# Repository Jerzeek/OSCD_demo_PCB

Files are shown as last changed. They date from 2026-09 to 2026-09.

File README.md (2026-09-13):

# OSCD Demo PCB

A demonstration / teaching PCB built by the [Open Science Community Delft](https://www.tudelft.nl/en/library/open-science-community-delft) to show what an open hardware project looks like in practice: full sources, an open licence, and everything needed to have the board made and reprogrammed by anyone.

It is a round, ~93 mm ESP32-C3 board shaped like the OSCD logo, with a ring of 12 addressable RGB LEDs, three sensors on a shared I²C bus, capacitive touch pads, and three push buttons. Plug it into USB-C, and the demo firmware lights the ring in response to tilt, touch, ambient light, and button presses.

| | |
|---|---|
| **Revision** | 1.0 |
| **Designer** | Dr. ir. Tim M. J. Nijssen, Open Science Community Delft |
| **Licence** | [CERN-OHL-P v2](LICENSE) (permissive) |
| **EDA tool** | KiCad (2026-era release — see [Opening the design](#opening-the-design)) |

---

## Features

| Block | Part | Interface |
|---|---|---|
| Microcontroller | ESP32-C3-MINI-1 (RISC-V, Wi-Fi + BLE, native USB) | — |
| RGB LEDs | 12 × WS2812B-2020, in a 63 mm ring | 1-wire, `GPIO8` |
| IMU | LSM6DS3 — 3-axis accelerometer + gyroscope | I²C `0x6A` |
| Ambient light | APDS-9306-065 | I²C `0x52` |
| Capacitive touch | MPR121 — 12 electrodes (6 buttons + 6-pad slider) | I²C `0x5A`, IRQ on `GPIO10` |
| Buttons | 3 × user push button, plus RESET and BOOT | `GPIO0/1/2` |
| Power | USB-C 5 V → HT7533-1 LDO → 3.3 V | — |
| Breakout | 2 × 2×5 pin header (5 V, 3.3 V, GND, 9 GPIO) | 2.54 mm |
| Test points | 5 V, 3.3 V, SDA, SCL (each via 100 Ω) | — |

There is no USB-UART bridge — the ESP32-C3's native USB peripheral is wired straight to the USB-C connector, protected by a USBLC6-2SC6 ESD array.

## Quick start

1. **Power it.** Connect a USB-C cable to `J1`. The board is bus-powered; no battery or jumper setting is needed.
2. **Install the toolchain.** Arduino IDE with the *esp32* board package by Espressif, board **ESP32C3 Dev Module**, and **Tools → USB CDC On Boot: Enabled**.
3. **Flash the demo.** Open [`firmware_examples/test_sensors/test_sensors.ino`](firmware_examples/test_sensors/test_sensors.ino) and upload it. Because there is no auto-reset circuit you must enter the bootloader by hand: **hold BOOT (SW2), tap RESET (SW1), release BOOT**, then click Upload. Tap RESET again when the upload finishes.
4. **Watch it.** The ring plays a rainbow sweep at boot, then reacts to tilt, touch, and the three buttons. Open the Serial Monitor at 115200 baud for sensor readings.

Full setup notes, required libraries, and troubleshooting are in [`firmware_examples/README.md`](firmware_examples/README.md).

## Pinout

| ESP32-C3 pin | Function on this board | Also on |
|---|---|---|
| `GPIO0` | Button **SW4** (active low, RC-debounced) | `J2.6` |
| `GPIO1` | Button **SW3** (active low, RC-debounced) | `J2.7` |
| `GPIO2` | Button **SW5** (active low, RC-debounced) | `J2.3` |
| `GPIO3` | APDS-9306 interrupt | `J2.4` |
| `GPIO4` | LSM6DS3 `INT1` | `J2.9` |
| `GPIO5` | LSM6DS3 `INT2` | `J3.3` |
| `GPIO6` | **I²C SCL** (4.7 kΩ pull-up) | `J3.4`, `TP5` |
| `GPIO7` | **I²C SDA** (4.7 kΩ pull-up) | `J3.5`, `TP6` |
| `GPIO8` | WS2812B data out → `D1` | `J3.6` |
| `GPIO9` | BOOT button **SW2** (strapping pin) | `J3.7` |
| `GPIO10` | MPR121 `IRQ` | `J2.8` |
| `GPIO18/19` | USB D− / D+ | — |
| `GPIO20/21` | UART0 RX / TX | `J3.8`, `J3.9` |
| `EN` | RESET button **SW1** | `J2.5` |

**Header pinouts** (2×5, 2.54 mm, odd/even numbering):

```
J2:  1 +5V    2 +3V3    3 GPIO2   4 GPIO3   5 EN
     6 GPIO0  7 GPIO1   8 GPIO10  9 GPIO4  10 GND

J3:  1 +5V    2 +3V3    3 GPIO5   4 GPIO6   5 GPIO7
     6 GPIO8  7 GPIO9   8 GPIO20  9 GPIO21 10 GND
```

**LED ring order:** `D1` sits at the 9 o'clock position and the chain `D1 → D2 → … → D12` runs clockwise, 30° apart.

**Touch electrodes:** `TP2` is the inner 6-pad slider on `ELE0…ELE5`; `TP1` is the outer ring of 6 buttons on `ELE6…ELE11`.

## Repository layout

```
OSCD_demo_PCB.kicad_pro     KiCad project
OSCD_demo_PCB.kicad_sch     Schematic (single sheet)
OSCD_demo_PCB.kicad_pcb     Board layout (4 layers)
schematic.pdf               Rendered schematic, for reading without KiCad
assets/
  OSCD_demo_PCB_symbols.kicad_sym    Project-local symbols
  OSCD_demo_PCB_footprints.pretty/   Project-local footprints (ESP32 module,
                                     touch pads, WS2812B-2020, logo, switches)
  graphics/                          OSCD logo artwork (DXF)
bom/ibom.html               Interactive HTML BOM for hand assembly
production/                 Fabrication outputs (gerbers, drill, BOM, CPL)
firmware_examples/          Arduino sketches
docs/                       Hardware and manufacturing documentation
```

## Opening the design

The sources were saved by a 2026-era KiCad release (schematic file format `20260306`, board format `20260206`). Open them with that release or newer; older KiCad versions will refuse the files.

Symbol and footprint libraries are project-local and resolved through `${KIPRJMOD}` in `sym-lib-table` / `fp-lib-table`, so cloning the repository and opening `OSCD_demo_PCB.kicad_pro` is enough — nothing has to be installed into your global libraries.

## Documentation

- **[docs/hardware.md](docs/hardware.md)** — how each subsystem works, jumper/configuration options, and design notes.
- **[docs/manufacturing.md](docs/manufacturing.md)** — board specification, ordering, and how to regenerate the fabrication files.
- **[firmware_examples/README.md](firmware_examples/README.md)** — toolchain setup, upload procedure, and what the demo does.

## Licence

Hardware and firmware are released under the **CERN Open Hardware Licence Version 2 – Permissive** ([`LICENSE`](LICENSE)). You may use, study, modify, manufacture and sell boards based on this design, including in closed-source products, provided you keep the copyright and licence notices and do not imply endorsement.

The OSCD logo and name are project branding; please replace them with your own if you distribute modified boards.

## Credits

Designed by Dr. ir. Tim M. J. Nijssen for the Open Science Community Delft.

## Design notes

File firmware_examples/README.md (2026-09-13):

# Firmware examples

Arduino sketches for the OSCD Demo PCB rev 1.0.

| Sketch | What it does |
|---|---|
| [`test_sensors/`](test_sensors) | Exercises every subsystem on the board — LEDs, IMU, light sensor, touch pads and buttons. Use it as a bring-up test and as a starting point for your own code. |

## Toolchain setup

1. Install the **Arduino IDE**.
2. **Boards Manager** → install **esp32** by Espressif Systems.
3. **Tools → Board** → *ESP32C3 Dev Module*.
4. **Tools → USB CDC On Boot** → **Enabled**. This is required. The board has no USB-UART bridge, so `Serial` runs over the ESP32-C3's native USB peripheral and will not appear at all if CDC is left disabled.
5. **Library Manager** → install:
   - `Adafruit NeoPixel`
   - `Adafruit LSM6DS` (pulls in `Adafruit_LSM6DS3TRC`)
   - `Adafruit Unified Sensor`
   - `Adafruit MPR121`

The APDS-9306-065 light sensor has no widely available Arduino library, so `test_sensors` talks to it directly over `Wire`. Those helpers live in [`test_sensors/APDS9306.h`](test_sensors/APDS9306.h) and double as a compact example of raw I²C register access.

## Uploading

There is no auto-reset circuit on this board, so the bootloader is entered by hand:

1. Close every open Serial Monitor — an open port blocks the upload.
2. **Hold BOOT (`SW2`).**
3. **Tap RESET (`SW1`).**
4. **Release BOOT.**
5. Click **Upload** in the IDE.
6. When the upload finishes, **tap RESET** to start the new firmware.

If the port does not appear, repeat steps 2–4; in bootloader mode the board enumerates under a different name than when running your sketch.

## What `test_sensors` does

On boot the ring plays a two-turn rainbow sweep, then the sketch runs continuously:

| Input | Effect |
|---|---|
| Buttons `SW3`/`SW4`/`SW5` | Each lights one third of the ring (4 LEDs) in its own hue while held |
| Tilt (LSM6DS3) | A red dot tracks the direction of gravity around the ring; brightness follows tilt magnitude |
| Ambient light (APDS-9306) | Scales overall ring brightness, so the board dims in a dark room |
| Touch pads (MPR121) | Each of the 12 electrodes lights its matching LED, brightness following touch strength |

Every 500 ms the sketch prints IMU, light and touch readings to **Serial at 115200 baud**. Each subsystem is probed at startup and reported as `[OK]` or `[FAIL]`, and the main loop skips whatever did not answer — so a single unpopulated or badly soldered sensor will not stop the rest of the board from working. That makes the sketch a useful first test on a freshly assembled board.

## Pin reference

```
I2C SDA        GPIO7    LSM6DS3 @0x6A, APDS-9306-065 @0x52, MPR121 @0x5A
I2C SCL        GPIO6
WS2812 data    GPIO8    12 LEDs, D1 at 9 o'clock, chain runs clockwise
Button SW3     GPIO1    active low
Button SW4     GPIO0    active low
Button SW5     GPIO2    active low
MPR121 IRQ     GPIO10   unused by this sketch
LSM6DS3 INT1   GPIO4    unused by this sketch
LSM6DS3 INT2   GPIO5    unused by this sketch
```

Buttons have external pull-ups and RC debouncing on the board, so `pinMode(pin, INPUT)` is correct — do not enable `INPUT_PULLUP`.

## Troubleshooting

| Symptom | Likely cause |
|---|---|
| No serial port at all | *USB CDC On Boot* is disabled, or a data-less charge-only USB-C cable |
| Upload fails / port vanishes | Serial Monitor still open, or the BOOT/RESET sequence was not held long enough |
| `[FAIL]` on one sensor | Solder bridge or open joint on that IC — check continuity on SDA/SCL at `TP6`/`TP5` |
| All I²C devices fail | `R15`/`R16` pull-ups missing, or `U4` not delivering 3.3 V (check `TP4`) |
| LEDs stay dark | Data path `GPIO8 → R22 → D1.DIN`, or `D16`/`D17`/`D18` not fitted |
| LEDs flicker or the board browns out | Ring brightness too high for a default-current USB port — lower `strip.setBrightness()` |

## Licence

CERN-OHL-P v2, same as the hardware. See [`LICENSE`](../LICENSE).

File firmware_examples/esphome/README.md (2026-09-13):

# ESPHome configuration

Turns the OSCD Demo PCB into a Home Assistant device with no C++ to write. Every peripheral on the board has a first-class ESPHome component, so the whole thing is one YAML file.

| File | Purpose |
|---|---|
| [`oscd_demo_pcb.yaml`](oscd_demo_pcb.yaml) | The device configuration |
| [`secrets.yaml.example`](secrets.yaml.example) | Template for Wi-Fi / API / OTA credentials |

## Requirements

**ESPHome 2026.6.0 or newer.** The `lsm6ds` motion platform this config uses for the IMU was added in 2026.6.0. The config declares `min_version`, so an older ESPHome refuses it with a clear message instead of failing halfway through a build.

```bash
pip install esphome
```

## First flash

```bash
cp secrets.yaml.example secrets.yaml   # then fill it in
esphome run oscd_demo_pcb.yaml
```

The board has no auto-reset circuit, so the **first** flash needs the bootloader entered by hand: **hold BOOT (`SW2`) → tap RESET (`SW1`) → release BOOT**, then start the upload. Tap RESET when it finishes.

After that first flash the board is on Wi-Fi and every subsequent update goes over OTA — the buttons are never needed again. On a board with no USB-UART bridge and no auto-reset, that is a real ergonomic win over the Arduino workflow.

`secrets.yaml` is gitignored. Do not commit it.

## What it exposes

| Entity | Source |
|---|---|
| **Ring** (light, 12 LEDs) | WS2812B chain on `GPIO8`, effects: Rainbow, Scan, Pulse, Touch trace |
| **Accel X/Y/Z**, **Roll**, **Pitch** | LSM6DS3 @ `0x6A` |
| **IMU Temperature** | LSM6DS3 on-chip sensor |
| **Ambient Light** (lux) | APDS-9306-065 @ `0x52` |
| **Slider 1–6** (binary) | MPR121 `ELE0`–`ELE5` — `TP2`, the inner slider |
| **Pad 1–6** (binary) | MPR121 `ELE6`–`ELE11` — `TP1`, the outer buttons |
| **Button SW3 / SW4 / SW5** | `GPIO1` / `GPIO0` / `GPIO2`, active low |
| **WiFi Signal**, **Uptime** | Diagnostics |

All of it is also reachable from the board's own web UI at `http://<device-ip>/` — see below.

`SW3` toggles the ring locally, so the board does something useful even with Home Assistant unreachable. The **Touch trace** effect reproduces the Arduino demo's behaviour — each electrode lights the LED nearest it, using the same pad-to-LED map worked out in `test_sensors.ino`.

## Board-specific settings worth understanding

These are the lines that are about *this* board rather than boilerplate. If you adapt the config, keep them.

- **`logger: hardware_uart: USB_SERIAL_JTAG`** — there is no USB-UART bridge, so logs go over the C3's native USB peripheral. This is the default on C3 and is written out only because it is the thing people most often get wrong on this chip.
- **`use_psram: false`** — the ESP32-C3-MINI-1 has no PSRAM. The LED component would otherwise try to use it.
- **`ignore_strapping_warning: true` on `GPIO8` and `GPIO2`** — both are ESP32-C3 strapping pins that must be high at reset. `R3` and `R2` (10 kΩ to 3V3) hold them there by design, so the warning is expected and is acknowledged rather than left to fire on every build. `R2` is also why the `SW5` pull-up `R8` is DNP.
- **No internal pull-ups on the buttons** — the board has external 10 kΩ pull-ups and 100 nF debounce caps.
- **`address: 0x5A` (MPR121) and `0x6A` (LSM6DS3)** — set by the fitted 0 Ω links `R21` and `R27`. If you re-jumper the board per [docs/hardware.md](../../docs/hardware.md#address-select-options), change these to match.

## Verification status

`esphome config` validates cleanly against **ESPHome 2026.8.2** with no warnings, and the firmware compiles clean — including the `addressable_lambda`, which config validation does not typecheck.

```
RAM:    34.1%  (109436 / 321296 bytes)
Flash:  60.0%  (1101716 / 1835008 bytes)
```

Flash includes ~101 KB for the embedded web UI (see [Demoing without Home Assistant](#demoing-without-home-assistant)); without `web_server` the build is 54.4%.

That leaves real headroom, which matters if you later add TLS or a VPN client — see [Running away from Home Assistant](#running-away-from-home-assistant). It has **not** been run on physical hardware — sensor readings, touch thresholds and the LED map are from the schematic and the Arduino demo, not from a bench test. Treat the touch `touch_threshold` / `release_threshold` values as starting points; the right numbers depend on your enclosure and how the board is held.

## Demoing without Home Assistant

The board serves its own UI, so it is fully demonstrable with nothing but a phone.

- **On your network:** browse to `http://<device-ip>/`.
- **Away from any known network:** the board fails to find one, raises its own access point (`OSCD Demo PCB Fallback`), and the same UI is at **`http://192.168.4.1/`**. Every entity is live — toggle the ring, pick effects, watch the sensors update.

### `local: true` is the setting that makes this work

Without it, the page loads its CSS and JS from `esphome.io` — exactly what you do not have while connected to the board's own AP. You would get a blank page at the worst possible moment.

With it, the UI is compiled into the firmware. Verified in the build: `USE_WEBSERVER_LOCAL` is defined, the generated `server_index_v3.h` asset is compiled in, and `web_server.cpp` serves it straight from flash. It costs ~101 KB of flash and essentially no RAM.

(`esphome config` still prints a `js_url` pointing at the CDN even with `local: true`. That value is vestigial — the embedded path does not use it. Do not let the config dump talk you out of this setting.)

### Two things to know before standing in front of an audience

**The fallback AP only appears if the board cannot reach a known network.** If you are demoing somewhere you have previously joined the Wi-Fi, it will connect to that instead and no AP will appear. It also takes a few seconds after power-up to give up and switch over. Test this in the room before you need it.

**`web_server` and `captive_portal` both want port 80.** In fallback-AP mode `web_server` takes it, which is what you want here — but it means the captive portal's Wi-Fi provisioning page is not reachable at the same time. This is a long-standing and somewhat version-dependent interaction upstream, so if a future ESPHome release flips the precedence, move the web UI to its own port and address them separately:

```yaml
web_server:
  port: 8080     # http://192.168.4.1:8080/ — captive portal keeps 80
```

Typing an IP and port skips DNS, so the captive portal cannot intercept it.

### OTA is off on the web UI

`ota: false` keeps firmware upload off a page you may hand to strangers. OTA still works through the Home Assistant API and the captive portal. If you want a password on the UI itself:

```yaml
web_server:
  auth:
    username: oscd
    password: !secret web_password
```

## Running away from Home Assistant

Short answer: **Home Assistant's external URL does not help here, because the connection runs the other way.**

The ESPHome native API is not a device that dials home. The device *listens* on TCP 6053, and Home Assistant *connects to it*. An external URL is what lets browsers and phones reach HA from outside — it is the opposite direction from what a remote device needs. Put the board on someone else's Wi-Fi and HA simply has nothing it can reach.

Three ways to actually do it, best first.

### 1. WireGuard on the device

ESPHome has a [`wireguard:`](https://esphome.io/components/wireguard/) component for ESP32. The board dials into your VPN, gets an address on it, and from HA's point of view is local again — the native API and everything else in this config keep working untouched.

```yaml
time:
  - platform: sntp     # REQUIRED — see below
    id: sntp_time

wireguard:
  address: 10.44.0.100
  netmask: 255.255.255.0
  private_key: !secret wg_private_key
  peer_endpoint: vpn.example.com
  peer_public_key: !secret wg_peer_public_key
  peer_port: 51820
  peer_allowed_ips:
    - 10.44.0.0/24
  peer_persistent_keepalive: 25s
  require_connection_to_proceed: true
```

Three things that catch people:

- **You must add an SNTP time source, and must _not_ use the `homeassistant` time platform.** WireGuard needs a synchronised clock to do its handshake, and getting the time from HA over the tunnel you have not established yet is a circular dependency that never resolves.
- **Auto-discovery usually fails.** Add the device manually in HA using its VPN address.
- **The ESP cannot set static routes.** `peer_allowed_ips` filters tunnel traffic, but actual routing follows `address`/`netmask` — outgoing connections only reach networks inside that range.

Only one peer is supported, which is fine for this use case.

### 2. MQTT

Swap the native API for [`mqtt:`](https://esphome.io/components/mqtt/). The device connects *out* to a broker, so it works from behind any NAT with no inbound access at all. HA subscribes to the same broker.

```yaml
mqtt:
  broker: mqtt.example.com
  port: 8883
  username: !secret mqtt_username
  password: !secret mqtt_password
  discovery: true
  certificate_authority: |
    -----BEGIN CERTIFICATE-----
    ... your broker's CA, in PEM ...
    -----END CERTIFICATE-----
```

**Delete the `api:` block when you do this.** If MQTT is enabled and the native API is configured but unused, the device reboots every 15 minutes waiting for an API connection that never arrives. Removing `api:` (or setting `reboot_timeout: 0s` on it) is the fix. This is the single most common way an otherwise-correct MQTT config goes wrong.

If you expose a broker to the internet, use TLS and real credentials. The CA block above is a placeholder — `esphome config` does not parse it, so a malformed certificate will validate happily and then fail on the device.

You also lose OTA-from-HA convenience and some native-API niceties.

### 3. Port-forward to the device

Forward 6053 from the remote site's router to the board. It works, and the API's Noise encryption means the traffic is protected — but you are exposing an IoT device's control port to the internet, and it is the option with the least margin for error. Prefer 1 or 2.

### Not really an option: pushing to the external URL

You *can* use `http_request` to POST sensor values to HA's REST API at its external URL with a long-lived access token. That genuinely uses the external URL — but it is one-way. Sensors would report; the ring would not be controllable from HA. Fine for a remote telemetry beacon, wrong for this board.

### Will it fit?

The base firmware uses 34% of RAM. WireGuard and MQTT-over-TLS both want a meaningful chunk on top — TLS handshakes are the expensive part — and the ESP32-C3-MINI-1 has no PSRAM to fall back on. There is headroom, but if you add either, check the build output rather than assuming.

Both variants above were validated with `esphome config` against ESPHome 2026.8.2. Neither has been run on hardware.

## Trade-off versus the Arduino sketch

ESPHome is declarative. Anything reactive and continuous — the tilt-to-LED mapping, brightness following ambient light — becomes a lambda, which is a worse place to teach from than [`test_sensors.ino`](../test_sensors/test_sensors.ino). Use ESPHome when you want the board to be a *device*; use the Arduino sketch when you want it to be an *example*.

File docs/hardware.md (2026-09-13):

# Hardware design notes

Reference for the OSCD Demo PCB rev 1.0. Designators match [`schematic.pdf`](../schematic.pdf) and the interactive BOM in [`bom/ibom.html`](../bom/ibom.html).

## Power

```
USB-C VBUS ──┬── U1 USBLC6-2SC6 (ESD)
             ├── TP3 (via R29 100R)
             ├── J2.1 / J3.1  (+5V to headers)
             ├── D16 / D17 / D18  1N5819WS ──► WS2812B VDD (3 groups of 4)
             └── U4 HT7533-1 (SOT-89 LDO) ──► +3V3 ──┬── U2 ESP32-C3-MINI-1
                                                     ├── U3 / U5 / U6 sensors
                                                     └── TP4 (via R30 100R)
```

The board is bus-powered from USB-C only; there is no battery input or charger.

**Why the Schottky diodes?** The WS2812B-2020 LEDs are fed from 5 V through `D16`/`D17`/`D18` rather than directly. Each diode drops roughly 0.3 V, putting LED V<sub>DD</sub> near 4.7 V. That brings the WS2812B logic-high threshold (~0.7 × V<sub>DD</sub>) down far enough that the ESP32-C3's 3.3 V data output is reliably recognised, without a level shifter. The 12 LEDs are split across three diodes so no single diode carries the full ring current.

`C12`–`C16` (10 µF) and `C17`/`C18` (100 nF) provide bulk and local decoupling; every IC has its own 100 nF.

## USB

`J1` is a 16-pin GCT USB4105 USB-C receptacle. `R4`/`R5` (5.1 kΩ) are the CC pull-downs that advertise the board as a UFP drawing default current. `R11` (1 MΩ) ties the shell to ground for HF bonding. `C11` (4.7 nF / 1 kV) is the shield-to-ground safety cap.

D+/D− pass through `U1` (USBLC6-2SC6 ESD array) and then `R9`/`R10` (0 Ω, fitted) to the ESP32-C3's `GPIO19`/`GPIO18`. The 0 Ω links exist so the USB pair can be cut and re-routed during bring-up.

There is **no USB-UART bridge and no auto-reset transistor pair.** Uploads go over the ESP32-C3's built-in USB serial/JTAG peripheral, and the bootloader must be entered manually with the BOOT and RESET buttons.

## Microcontroller

`U2` is an ESP32-C3-MINI-1 module (integrated antenna, 4 MB flash). Strapping/reset support:

| Part | Net | Purpose |
|---|---|---|
| `R1` 10 kΩ | `EN` → 3V3 | Reset pull-up; `SW1` pulls `EN` low |
| `R12` 10 kΩ | `GPIO9` → 3V3 | BOOT strapping pull-up; `SW2` pulls it low |
| `R2` 10 kΩ | `GPIO2` → 3V3 | Strapping pin must be high at boot |
| `R3` 10 kΩ | `GPIO8` → 3V3 | Strapping pin must be high at boot |

Because `GPIO2` and `GPIO8` are strapping pins that carry the pull-ups above, they are safe to use as inputs/outputs after boot but must not be held low at reset — `GPIO8` in particular is the LED data line, so keep the ring quiet until firmware starts.

## User buttons

| Button | Net | Pull-up | Debounce |
|---|---|---|---|
| `SW3` | `GPIO1` via `R34` (0 Ω) | `R6` 10 kΩ | `C6` 100 nF |
| `SW4` | `GPIO0` via `R33` (0 Ω) | `R7` 10 kΩ | `C7` 100 nF |
| `SW5` | `GPIO2` via `R31` (0 Ω) | **`R8` is DNP** | `C8` 100 nF |

All three are active low, so firmware uses plain `INPUT` (no internal pull-up needed). `R8` is deliberately not fitted: `GPIO2` already carries the strapping pull-up `R2`, and a second 10 kΩ in parallel would only halve the pull-up value.

`SW1` (RESET) and `SW2` (BOOT) are the small SMD tactile switches `TS-1088-AR02016`; the three user buttons are the larger through-hole-style `PTS645`.

## I²C bus

One 400 kHz bus on `GPIO7` (SDA) and `GPIO6` (SCL), pulled up by `R15`/`R16` (4.7 kΩ) and brought out to `TP6`/`TP5` through 100 Ω series resistors for safe scope probing.

| Device | Address | Interrupt |
|---|---|---|
| `U3` LSM6DS3 IMU | `0x6A` | `INT1` → `GPIO4`, `INT2` → `GPIO5` (via 0 Ω `R24`/`R23`) |
| `U5` APDS-9306-065 light sensor | `0x52` | `INT` → `GPIO3` (via 0 Ω `R25`) |
| `U6` MPR121 touch controller | `0x5A` | `IRQ` → `GPIO10` (via 0 Ω `R32`) |

The interrupt lines are wired but unused by the demo firmware — they are there for anyone who wants to move from polling to interrupt-driven reads.

### Address-select options

Both configurable devices are set by 0 Ω links, so the addresses can be changed with a soldering iron rather than a re-spin.

**MPR121 (`U6`) `ADDR` pin** — fit exactly one:

| Link | `ADDR` tied to | Resulting address |
|---|---|---|
| `R21` ✅ *fitted* | GND | `0x5A` |
| `R18` (+ `R28` 10 kΩ) | 3V3 | `0x5B` |
| `R20` | SCL | `0x5C` |
| `R19` | SDA | `0x5D` |

**LSM6DS3 (`U3`) `SDO/SA0` pin** — fit exactly one:

| Link | `SA0` tied to | Resulting address |
|---|---|---|
| `R27` ✅ *fitted* | GND | `0x6A` |
| `R26` (+ `R14` 10 kΩ) | 3V3 | `0x6B` |

`R13` (10 kΩ) holds the IMU's `CS` high, selecting I²C mode. `U3`'s `SDX`/`SCX` are grounded (no auxiliary sensor hub device).

## LED ring

Twelve WS2812B-2020 LEDs on a 63 mm-diameter circle, 30° apart, `D1` at the 9 o'clock position with the data chain running clockwise `D1 → D12`. `D12`'s `DOUT` is unterminated. Data enters `D1` through `R22` (0 Ω) from `GPIO8`.

At full white and full brightness twelve WS2812Bs draw well over half an amp, which a USB-C default-current port may not like. The demo firmware caps brightness (`strip.setBrightness()`), and you should too.

## Capacitive touch

`U6` (MPR121) drives twelve electrodes etched directly into the top copper as custom footprints:

| Footprint | Designator | Electrodes | Shape |
|---|---|---|---|
| `6_pad_touch_slider` | `TP2` | `ELE0`–`ELE5` | Inner 6-segment slider |
| `6_pad_touch_buttons` | `TP1` | `ELE6`–`ELE11` | Outer 6 discrete buttons |

`R17` (75 kΩ, 1 %) is the `REXT` reference resistor that sets the MPR121's charge current — do not substitute a loose-tolerance part. The electrode nets are assigned to the `CAP` net class (0.1 mm tracks) to keep parasitic capacitance low and consistent.

## Test points

| TP | Signal | Series resistor |
|---|---|---|
| `TP3` | +5 V | `R29` 100 Ω |
| `TP4` | +3.3 V | `R30` 100 Ω |
| `TP5` | SCL | `R35` 100 Ω |
| `TP6` | SDA | `R36` 100 Ω |

The 100 Ω resistors limit fault current if a probe slips, so a short at a test point cannot damage the bus or the regulator.

## Board construction

- **4 layers:** `F.Cu` (signal) / `In1.Cu` (power) / `In2.Cu` (power) / `B.Cu` (signal)
- **Stackup:** 0.035 / 0.1 prepreg / 0.035 / 1.24 core / 0.035 / 0.1 prepreg / 0.035 mm → **1.6 mm** finished
- **Outline:** the OSCD logo silhouette, roughly 93 × 93 mm
- **Assembly:** single-sided — every component is on the top layer

**Net classes**

| Class | Track width | Via | Applied to |
|---|---|---|---|
| `Default` | 0.15 mm | 0.45 / 0.3 mm | everything else |
| `PWR` | 0.40 mm | 0.60 / 0.3 mm | `+5V`, `+3.3V`, `GND`, LED V<sub>DD</sub> nets |
| `CAP` | 0.10 mm | — | MPR121 electrode nets |

## Known quirks in rev 1.0

- `J2` and `J3` carry the Value field `Conn_01x12` while the symbol and footprint are both 2×5 (10-pin). The netlist and layout are correct; only the displayed value string is wrong, and it propagates into `production/bom.csv`. Worth fixing before a rev 1.1.
- `R8` is DNP by design (see [User buttons](#user-buttons)) and so does not appear in `production/bom.csv`.
- `R14`, `R28` and `R13` are fitted, but `R14`/`R28` only do anything if the matching address-select link (`R26`/`R18`) is also fitted.

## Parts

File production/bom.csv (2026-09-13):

Designator | Footprint | Quantity | Value | LCSC Part #
C1 | 0805 | 1 | 1u | C28323
C11 | 0805 | 1 | 4.7n/1kV | C565695
C12, C13, C14, C15, C16, C2 | 0805 | 6 | 10u | C15850
C17, C18, C3, C4, C5, C6, C7, C8 | 0805 | 8 | 100n | C49678
D1, D10, D11, D12, D2, D3, D4, D5, D6, D7, D8, D9 | LED_WS2812B-2020_PLCC4_2.0x2.0mm | 12 | WS2812B | C2976072
D16, D17, D18 | D_SOD-323 | 3 | 1N5819WS | C191023
J1 | USB_C_Receptacle_GCT_USB4105-xx-A_16P_TopMnt_Horizontal | 1 | USB_C_Receptacle_USB2.0_16P | C393939
J2, J3 | PinHeader_2x05_P2.54mm_Vertical | 2 | Conn_01x12
R1, R12, R13, R14, R2, R28, R3, R6, R7 | 0805 | 9 | 10k | C17414
R10, R21, R22, R23, R24, R25, R27, R31, R32, R33, R34, R9 | 0805 | 12 | 0R | C17477
R11 | 0805 | 1 | 1M | C17514
R15, R16 | 0805 | 2 | 4k7 | C17673
R17 | 0805 | 1 | 75k/1% | C17819
R29, R30, R35, R36 | 0805 | 4 | 100R | C17408
R4, R5 | 0805 | 2 | 5k1 | C27834
SW1 | SMD_SW_1P1T_TS-1088-AR02016 | 1 | RESET | C720477
SW2 | SMD_SW_1P1T_TS-1088-AR02016 | 1 | BOOT | C720477
SW3, SW4, SW5 | SW_SPST_PTS645Sx43SMTR92 | 3 | PB | C2837531
U1 | SOT-23-6 | 1 | USBLC6-2SC6 | C7519
U2 | ESP32-C3-MINI-1 | 1 | ESP32-C3-MINI-1 | C2838502
U3 | LGA-14_3x2.5mm_P0.5mm_LayoutBorder3x4y | 1 | LSM6DS3 | C967633
U4 | SOT-89-3 | 1 | HT7533-1-SOT89 | C14289
U5 | Broadcom_DFN-6_2x2mm_P0.65mm | 1 | APDS-9306-065 | C2649498
U6 | UQFN-20_3x3mm_P0.4mm | 1 | MPR121QR2 | C91322

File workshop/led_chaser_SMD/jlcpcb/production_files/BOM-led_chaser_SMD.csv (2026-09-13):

Comment | Designator | Footprint | LCSC | Quantity
100k | RV1 | Potentiometer_Bourns_TC33X_Vertical | C48997895 | 1
10k | R1,R4 | R_0805_2012Metric_Pad1.20x1.40mm_HandSolder | C17414 | 2
10nF | C2,C3,C4 | C_0805_2012Metric_Pad1.18x1.45mm_HandSolder | C1710 | 3
10uF | C1,C5 | C_0805_2012Metric_Pad1.18x1.45mm_HandSolder | C15850 | 2
1N5819 | D11 | D_SOD-323 | C191023 | 1
1k | R2,R3 | R_0805_2012Metric_Pad1.20x1.40mm_HandSolder | C17513 | 2
4017 | U2 | SOIC-16_3.9x9.9mm_P1.27mm | C2868374 | 1
ENABLE | SW1 | SW_DIP_SPSTx01_Slide_6.7x4.1mm_W8.61mm_P2.54mm_LowProfile | C600988 | 1
LED | D1,D10,D2,D3,D4,D5,D6,D7,D8,D9 | LED_0805_2012Metric_Pad1.15x1.40mm_HandSolder | C84256 | 10
NE555 | U1 | SOIC-8_3.9x4.9mm_P1.27mm | C7593 | 1

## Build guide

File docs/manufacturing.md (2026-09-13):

# Manufacturing

Everything needed to have OSCD Demo PCB rev 1.0 built is already committed under [`production/`](../production). You do not need KiCad to order a board — only to change the design.

## Board specification

Quote the board with these parameters:

| Parameter | Value |
|---|---|
| Layers | 4 |
| Dimensions | ~93 × 93 mm, non-rectangular outline (see `Edge.Cuts`) |
| Thickness | 1.6 mm |
| Stackup | 0.035 / 0.1 / 0.035 / 1.24 / 0.035 / 0.1 / 0.035 mm, FR4 (ε<sub>r</sub> 4.5) |
| Copper weight | 1 oz outer |
| Minimum track / clearance | 0.10 mm / 0.15 mm |
| Minimum via | 0.45 mm pad / 0.30 mm drill |
| Surface finish | Lead-free HASL (as designed; ENIG is a drop-in upgrade and gives flatter touch pads) |
| Solder mask | Blue (as designed — any colour works) |
| Silkscreen | White |
| Assembly | Single-sided, top only |

The outline is the OSCD logo silhouette, so expect a routing (not V-score) charge and check that your fabricator accepts the internal radii.

## What is in `production/`

| File | Purpose |
|---|---|
| `gerber.zip` | RS-274X gerbers for all four copper layers, mask, silkscreen, paste, edge cuts, plus PTH/NPTH Excellon drill files and drill maps |
| `bom.csv` | Bill of materials grouped by value, with LCSC part numbers |
| `positions.csv` | Pick-and-place / CPL file (`Designator, Mid X, Mid Y, Rotation, Layer`) |
| `designators.csv` | Designator-to-quantity list |
| `netlist.ipc` | IPC-D-356 netlist, for fabricator electrical test |

The BOM carries LCSC part numbers throughout, so the design drops straight into JLCPCB's assembly service. Two caveats before you upload:

- **`J2`/`J3` have no LCSC number.** They are ordinary 2×5, 2.54 mm pin headers — source them yourself and solder them by hand, or leave them off entirely if you do not need the breakout.
- **`R8` is intentionally absent** from the BOM (see [hardware.md](hardware.md#user-buttons)). This is correct, not an omission.

## Hand assembly

Open [`bom/ibom.html`](../bom/ibom.html) in a browser for an interactive board view that highlights each part as you work through the list. It is a self-contained file — no server or internet needed.

Everything is 0805 or larger apart from the ICs, which are LGA-14 (`U3`), DFN-6 (`U5`), UQFN-20 (`U6`) and the 2020-size WS2812Bs. Those want a stencil, solder paste and a hotplate or reflow oven; the passives, headers and buttons are comfortable with an iron.

Order of work that tends to go smoothly: reflow the ICs and LEDs first, then hand-solder `J1`, the buttons and the headers, then power the board from a current-limited supply and check `TP4` reads 3.3 V before plugging it into a computer.

## Regenerating the fabrication files

The contents of `production/` are produced by the **Fabrication Toolkit** KiCad plugin; its settings are stored in [`fabrication-toolkit-options.json`](../fabrication-toolkit-options.json) at the project root. Open the board in Pcbnew and run the plugin — it re-exports the whole folder in one pass, targeting JLCPCB conventions (including footprint rotation correction).

The other generated artefacts:

- **`bom/ibom.html`** — the *Interactive HTML BOM* plugin, run from Pcbnew.
- **`schematic.pdf`** — Eeschema, *File → Plot*, PDF output.

Regenerate all three whenever the schematic or layout changes, and commit them together with the source files so the repository always describes one consistent revision.

## Before you re-spin

Run **DRC in Pcbnew** and **ERC in Eeschema** and resolve or explicitly acknowledge everything. Then check that the outputs above were regenerated — a `production/` folder that predates the last board edit is the most common way an open hardware repository ships an unbuildable design.

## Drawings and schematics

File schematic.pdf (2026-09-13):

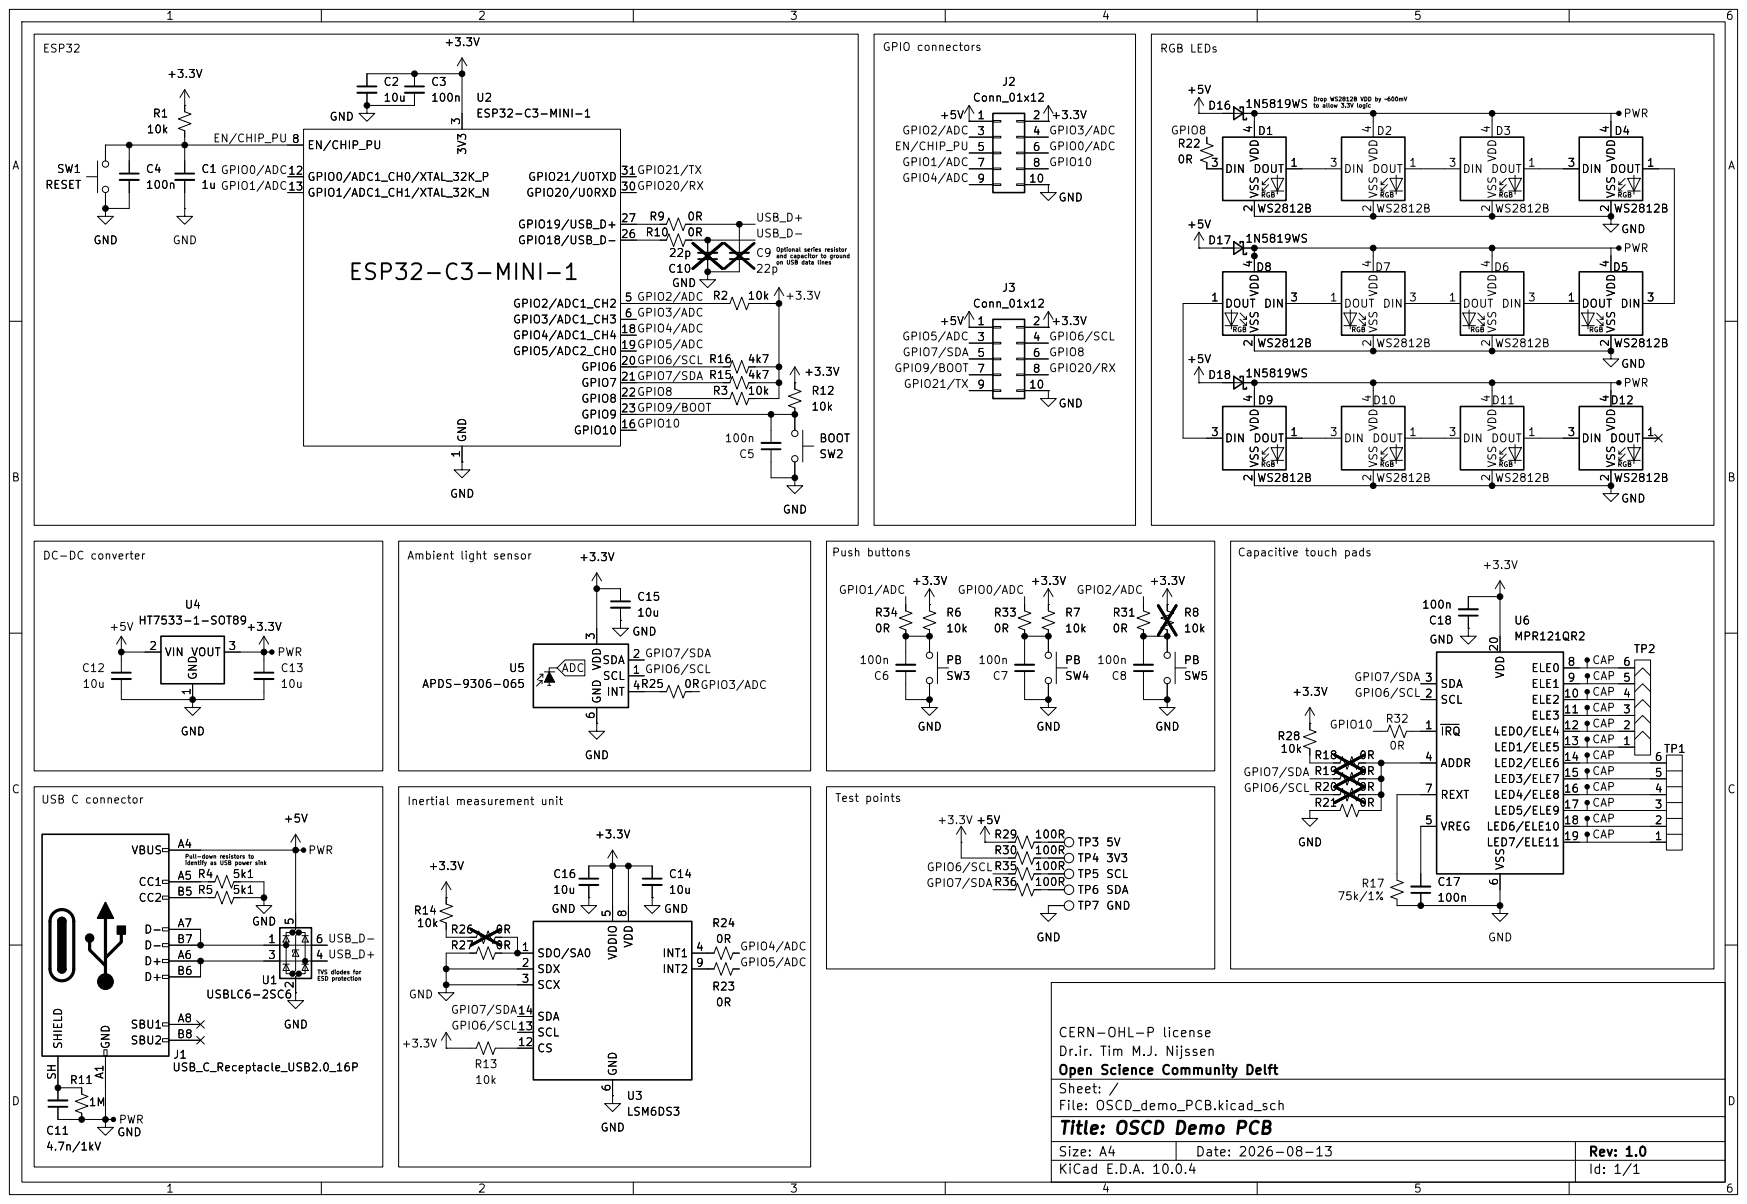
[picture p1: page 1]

to allow 3.3V logic Capacitive touch pads

Optional series resistor and capacitor to ground

Pull-down resistors to

CERN-OHL-P license
Dr.ir. Tim M.J. Nijssen
Open Science Community Delft
Sheet: /
File: OSCD_demo_PCB.kicad_sch
Title: OSCD Demo PCB

Size: A4 | Rev: 1.0
KiCad E.D.A. 10.0.4 | Id: 1/1

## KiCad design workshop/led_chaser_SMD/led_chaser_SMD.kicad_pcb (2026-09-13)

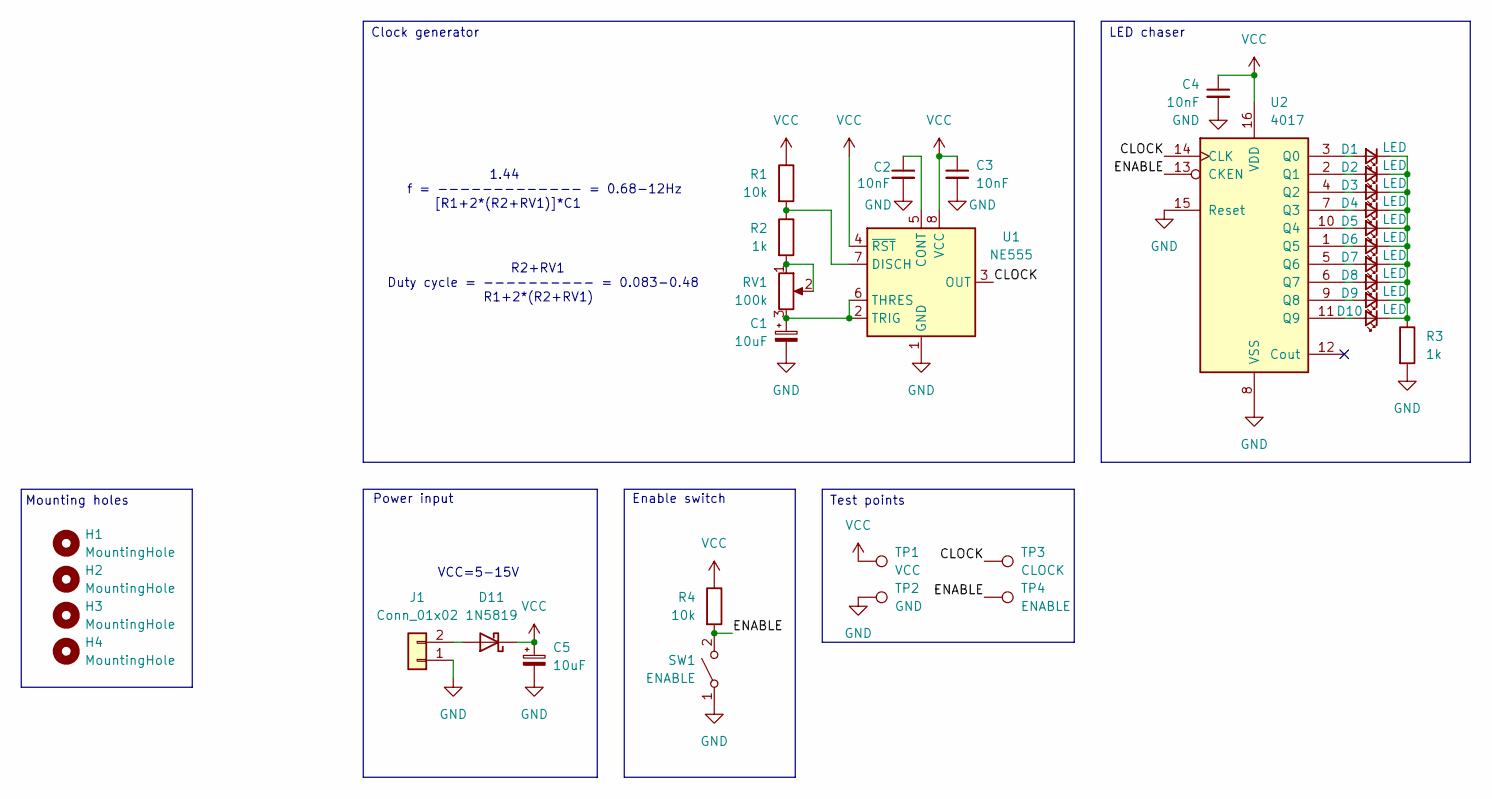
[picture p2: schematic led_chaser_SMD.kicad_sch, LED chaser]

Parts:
C1, C5: 10uF; C_0805_2012Metric_Pad1.18x1.45mm_HandSolder
C2, C3, C4: 10nF; C_0805_2012Metric_Pad1.18x1.45mm_HandSolder
D1, D2, D3, D4, D5, D6, D7, D8, D9, D10: LED; LED_0805_2012Metric_Pad1.15x1.40mm_HandSolder
D11: 1N5819; D_SOD-323
H1, H2, H3, H4: MountingHole; MountingHole_3.2mm_M3
J1: Conn_01x02; JST_XH_B2B-XH-A_1x02_P2.50mm_Vertical
R1, R4: 10k; R_0805_2012Metric_Pad1.20x1.40mm_HandSolder
R2, R3: 1k; R_0805_2012Metric_Pad1.20x1.40mm_HandSolder
RV1: 100k; Potentiometer_Bourns_TC33X_Vertical
SW1: ENABLE; SW_DIP_SPSTx01_Slide_6.7x4.1mm_W8.61mm_P2.54mm_LowProfile
TP1: VCC; TestPoint_Pad_D2.0mm
TP2: GND; TestPoint_Pad_D2.0mm
TP3: CLOCK; TestPoint_Pad_D2.0mm
TP4: ENABLE; TestPoint_Pad_D2.0mm
U1: NE555; SOIC-8_3.9x4.9mm_P1.27mm
U2: 4017; SOIC-16_3.9x9.9mm_P1.27mm

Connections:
/CLOCK: TP3.1 (1_1), U1.3 (OUT), U2.14 (CLK)
/ENABLE: R4.2, SW1.2 (B), TP4.1 (1_1), U2.13 (CKEN)
GND: C1.2, C2.2, C3.2, C4.2, C5.2, J1.1, R3.2, SW1.1 (A), TP2.1 (1_1), U1.1 (GND), U2.8 (VSS), U2.15 (Reset)
unnamed: D1.2 (A), U2.3 (Q0)
unnamed: D1.1 (K), D2.1 (K), D3.1 (K), D4.1 (K), D5.1 (K), D6.1 (K), D7.1 (K), D8.1 (K), D9.1 (K), D10.1 (K), R3.1
unnamed: D2.2 (A), U2.2 (Q1)
unnamed: D3.2 (A), U2.4 (Q2)
unnamed: D4.2 (A), U2.7 (Q3)
unnamed: D5.2 (A), U2.10 (Q4)
unnamed: D6.2 (A), U2.1 (Q5)
unnamed: D7.2 (A), U2.5 (Q6)
unnamed: D8.2 (A), U2.6 (Q7)
unnamed: D9.2 (A), U2.9 (Q8)
unnamed: D10.2 (A), U2.11 (Q9)
unnamed: D11.2 (A), J1.2
unnamed: R2.2, RV1.1, RV1.2
unnamed: C2.1, U1.5 (CONT)
unnamed: R1.2, R2.1, U1.7 (DISCH)
unnamed: C1.1, RV1.3, U1.2 (TRIG), U1.6 (THRES)
VCC: C3.1, C4.1, C5.1, D11.1 (K), R1.1, R4.1, TP1.1 (1_1), U1.4 (~RST), U1.8 (VCC), U2.16 (VDD)

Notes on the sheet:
Enable switch
LED chaser
R2+RV1 Duty cycle = ---------- = 0.083-0.48 R1+2*(R2+RV1)
1.44 f = ------------- = 0.68-12Hz [R1+2*(R2+RV1)]*C1
Test points
Clock generator
Mounting holes
Power input
VCC=5-15V

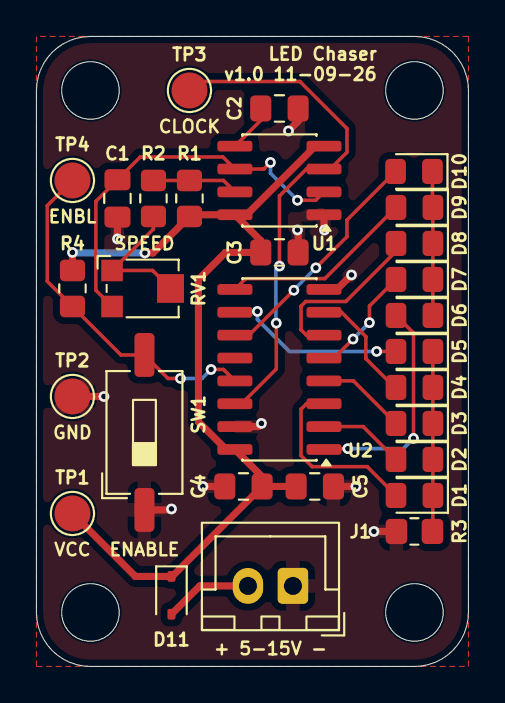
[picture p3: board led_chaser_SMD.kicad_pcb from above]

Board: 2 copper layers, 24.0 x 35.0 mm, 33 parts (0 on the bottom side), 20 nets.

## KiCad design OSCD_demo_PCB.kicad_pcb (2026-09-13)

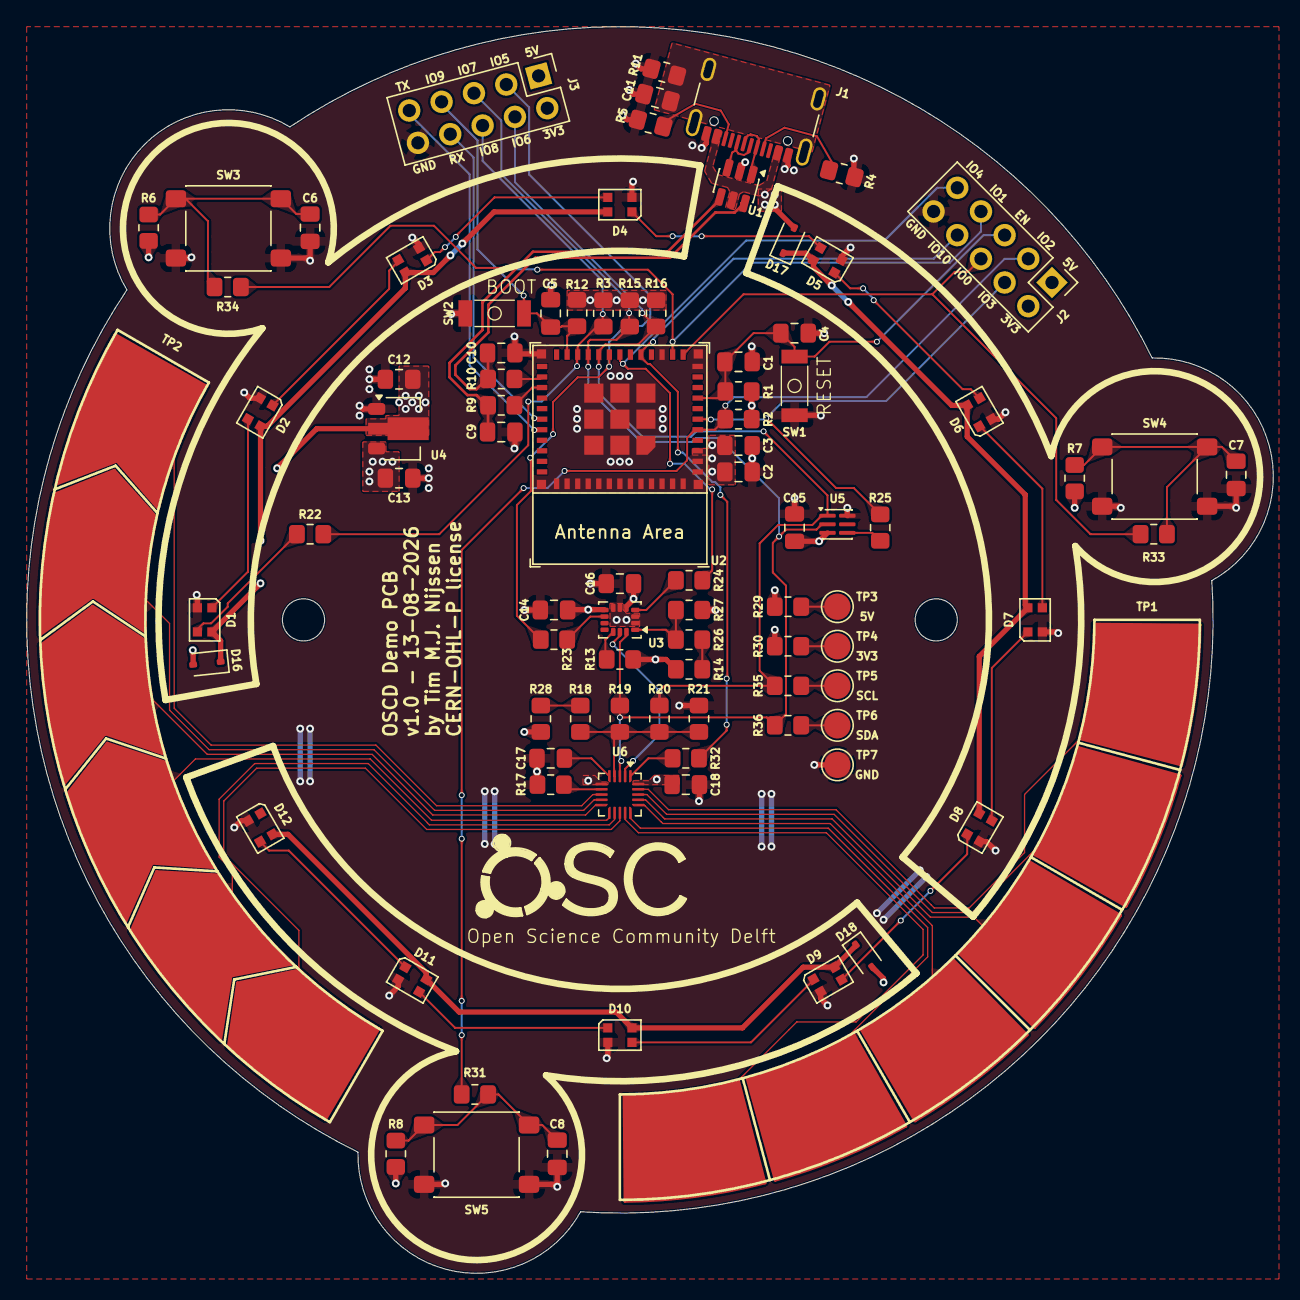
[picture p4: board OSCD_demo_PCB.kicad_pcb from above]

Board: 4 copper layers, 94.6 x 94.6 mm, 90 parts (0 on the bottom side), 71 nets.

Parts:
C1: 1u; C_0805_2012Metric_Pad1.18x1.45mm_HandSolder
C2, C12, C13, C14, C15, C16: 10u; C_0805_2012Metric_Pad1.18x1.45mm_HandSolder
C3, C4, C5, C6, C7, C8, C17, C18: 100n; C_0805_2012Metric_Pad1.18x1.45mm_HandSolder
C9, C10: 22p; C_0805_2012Metric_Pad1.18x1.45mm_HandSolder
C11: 4.7n/1kV; C_0805_2012Metric_Pad1.18x1.45mm_HandSolder
D1, D2, D3, D4, D5, D6, D7, D8, D9, D10, D11, D12: WS2812B; LED_WS2812B-2020_PLCC4_2.0x2.0mm
D16, D17, D18: 1N5819WS; D_SOD-323
J1: USB_C_Receptacle_USB2.0_16P; USB_C_Receptacle_GCT_USB4105-xx-A_16P_TopMnt_Horizontal
J2, J3: Conn_01x12; PinHeader_2x05_P2.54mm_Vertical
R1, R2, R3, R6, R7, R8, R12, R13, R14, R28: 10k; R_0805_2012Metric_Pad1.20x1.40mm_HandSolder
R4, R5: 5k1; R_0805_2012Metric_Pad1.20x1.40mm_HandSolder
R9, R10, R18, R19, R20, R21, R22, R23, R24, R25, R26, R27, R31, R32, R33, R34: 0R; R_0805_2012Metric_Pad1.20x1.40mm_HandSolder
R11: 1M; R_0805_2012Metric_Pad1.20x1.40mm_HandSolder
R15, R16: 4k7; R_0805_2012Metric_Pad1.20x1.40mm_HandSolder
R17: 75k/1%; R_0805_2012Metric_Pad1.20x1.40mm_HandSolder
R29, R30, R35, R36: 100R; R_0805_2012Metric_Pad1.20x1.40mm_HandSolder
SW1: RESET; SMD_SW_1P1T_TS-1088-AR02016
SW2: BOOT; SMD_SW_1P1T_TS-1088-AR02016
SW3, SW4, SW5: PB; SW_SPST_PTS645Sx43SMTR92
TP1: 6_pad_touch_slider; 6_pad_touch_buttons
TP2: 6_pad_touch_slider
TP3: 5V; TestPoint_Pad_D2.0mm
TP4: 3V3; TestPoint_Pad_D2.0mm
TP5: SCL; TestPoint_Pad_D2.0mm
TP6: SDA; TestPoint_Pad_D2.0mm
TP7: GND; TestPoint_Pad_D2.0mm
U1: USBLC6-2SC6; SOT-23-6
U2: ESP32-C3-MINI-1
U3: LSM6DS3; LGA-14_3x2.5mm_P0.5mm_LayoutBorder3x4y
U4: HT7533-1-SOT89; SOT-89-3
U5: APDS-9306-065; Broadcom_DFN-6_2x2mm_P0.65mm
U6: MPR121QR2; UQFN-20_3x3mm_P0.4mm

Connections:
+3.3V: C2.1, C3.1, C13.1, C14.1, C15.1, C16.1, C18.2, J2.2, J3.2, R1.1, R2.2, R3.2, R6.2, R7.2, R8.2, R12.1, R13.1, R14.2, R15.2, R16.2, R28.2, R30.1, U2.3 (3V3), U3.5 (VDDIO), U3.8 (VDD), U4.3 (VOUT), U5.3 (VDD), U6.20 (VDD)
+5V: C12.1, D16.2 (A), D17.2 (A), D18.2 (A), J1.A4 (VBUS), J1.A9 (VBUS), J1.B4 (VBUS), J1.B9 (VBUS), J2.1, J3.1, R29.1, U1.5 (VBUS), U4.2 (VIN)
/EN/CHIP_PU: C1.1, C4.1, J2.5, R1.2, SW1.2, U2.8 (EN/CHIP_PU)
/GPIO0/ADC: J2.6, R33.1, U2.12 (GPIO0/ADC1_CH0/XTAL_32K_P)
/GPIO1/ADC: J2.7, R34.1, U2.13 (GPIO1/ADC1_CH1/XTAL_32K_N)
/GPIO2/ADC: J2.3, R2.1, R31.1, U2.5 (GPIO2/ADC1_CH2)
/GPIO3/ADC: J2.4, R25.1, U2.6 (GPIO3/ADC1_CH3)
/GPIO4/ADC: J2.9, R24.1, U2.18 (GPIO4/ADC1_CH4)
/GPIO5/ADC: J3.3, R23.1, U2.19 (GPIO5/ADC2_CH0)
/GPIO6/SCL: J3.4, R16.1, R20.2, R35.1, U2.20 (GPIO6), U3.13 (SCL), U5.1 (SCL), U6.2 (SCL)
/GPIO7/SDA: J3.5, R15.1, R19.2, R36.1, U2.21 (GPIO7), U3.14 (SDA), U5.2 (SDA), U6.3 (SDA)
/GPIO8: J3.6, R3.1, R22.1, U2.22 (GPIO8)
/GPIO9/BOOT: C5.2, J3.7, R12.2, SW2.1, U2.23 (GPIO9)
/GPIO10: J2.8, R32.2, U2.16 (GPIO10)
/GPIO20/RX: J3.8, U2.30 (GPIO20/U0RXD)
/GPIO21/TX: J3.9, U2.31 (GPIO21/U0TXD)
/USB_D+: C9.2, R9.2, U1.4 (I/O2)
/USB_D-: C10.2, R10.2, U1.6 (I/O1)
GND: C1.2, C2.2, C3.2, C4.2, C5.1, C6.1, C7.1, C8.1, C9.1, C10.1, C11.1, C12.2, C13.2, C14.2, C15.2, C16.2, C17.1, C18.1, D1.2 (VSS), D2.2 (VSS), D3.2 (VSS), D4.2 (VSS), D5.2 (VSS), D6.2 (VSS), D7.2 (VSS), D8.2 (VSS), D9.2 (VSS), D10.2 (VSS), D11.2 (VSS), D12.2 (VSS), J1.A1 (GND), J1.A12 (GND), J1.B1 (GND), J1.B12 (GND), J2.10, J3.10, R4.2, R5.2, R11.1, R17.1, R21.2, R27.2, SW1.1, SW2.2, SW3.2, SW4.2, SW5.2, TP7.1 (1_1), U1.2 (GND), U2.1 (GND), U2.2 (GND), U2.11 (GND), U2.14 (GND), U2.36 (GND), U2.37 (GND), U2.38 (GND), U2.39 (GND), U2.40 (GND), U2.41 (GND), U2.42 (GND), U2.43 (GND), U2.44 (GND), U2.45 (GND), U2.46 (GND), U2.47 (GND), U2.48 (GND), U2.49 (GND), U2.50 (GND), U2.51 (GND), U2.52 (GND), U2.53 (GND), U3.2 (SDX), U3.3 (SCX), U3.6 (GND), U3.7 (GND), U4.1 (GND), U5.6 (GND), U6.6 (VSS)
unnamed: C6.2, R6.1, R34.2, SW3.1
unnamed: C7.2, R7.1, R33.2, SW4.1
unnamed: C8.2, R8.1, R31.2, SW5.1
unnamed: D1.3 (DIN), R22.2
unnamed: D1.1 (DOUT), D2.3 (DIN)
unnamed: D1.4 (VDD), D2.4 (VDD), D3.4 (VDD), D4.4 (VDD), D16.1 (K)
unnamed: D2.1 (DOUT), D3.3 (DIN)
unnamed: D3.1 (DOUT), D4.3 (DIN)
unnamed: D4.1 (DOUT), D5.3 (DIN)
unnamed: D5.1 (DOUT), D6.3 (DIN)
unnamed: D6.1 (DOUT), D7.3 (DIN)
unnamed: D7.1 (DOUT), D8.3 (DIN)
unnamed: D8.1 (DOUT), D9.3 (DIN)
unnamed: D9.1 (DOUT), D10.3 (DIN)
unnamed: D10.1 (DOUT), D11.3 (DIN)
unnamed: D9.4 (VDD), D10.4 (VDD), D11.4 (VDD), D12.4 (VDD), D18.1 (K)
unnamed: D11.1 (DOUT), D12.3 (DIN)
unnamed: D5.4 (VDD), D6.4 (VDD), D7.4 (VDD), D8.4 (VDD), D17.1 (K)
unnamed: J1.A5 (CC1), R4.1
unnamed: J1.B5 (CC2), R5.1
unnamed: J1.A6 (D+), J1.B6 (D+), U1.3 (I/O2)
unnamed: J1.A7 (D-), J1.B7 (D-), U1.1 (I/O1)
unnamed: C11.2, J1.SH (SHIELD), R11.2
unnamed: R14.1, R26.2
unnamed: R18.2, R28.1
unnamed: R29.2, TP3.1 (1_1)
unnamed: R30.2, TP4.1 (1_1)
unnamed: R35.2, TP5.1 (1_1)
unnamed: R36.2, TP6.1 (1_1)
unnamed: R10.1, U2.26 (GPIO18/USB_D-)
unnamed: R9.1, U2.27 (GPIO19/USB_D+)
unnamed: R13.2, U3.12 (CS)
unnamed: R24.2, U3.4 (INT1)
unnamed: R23.2, U3.9 (INT2)
unnamed: R26.1, R27.1, U3.1 (SDO/SA0)
unnamed: R25.2, U5.4 (INT)
unnamed: R18.1, R19.1, R20.1, R21.1, U6.4 (ADDR)
unnamed: TP2.6 (Pad_6), U6.8 (ELE0)
unnamed: TP2.5 (Pad_5), U6.9 (ELE1)
unnamed: TP2.4 (Pad_4), U6.10 (ELE2)
unnamed: TP2.3 (Pad_3), U6.11 (ELE3)
unnamed: TP2.2 (Pad_2), U6.12 (LED0/ELE4)
unnamed: TP2.1 (Pad_1), U6.13 (LED1/ELE5)
unnamed: TP1.6 (Pad_6), U6.14 (LED2/ELE6)
unnamed: TP1.5 (Pad_5), U6.15 (LED3/ELE7)
unnamed: TP1.4 (Pad_4), U6.16 (LED4/ELE8)
unnamed: TP1.3 (Pad_3), U6.17 (LED5/ELE9)
unnamed: TP1.2 (Pad_2), U6.18 (LED6/ELE10)
unnamed: TP1.1 (Pad_1), U6.19 (LED7/ELE11)
unnamed: R17.2, U6.7 (REXT)
unnamed: C17.2, U6.5 (VREG)
unnamed: R32.1, U6.1 (~IRQ)

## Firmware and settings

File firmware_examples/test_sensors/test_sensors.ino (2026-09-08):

/*  OSCD Demo PCB — Firmware demo
 *  Open Science Community Delft
 *  
 *  v1.0, 07-09-2026, Dr.ir. Tim M.J. Nijssen
 *  CERN-OHL-P license
 *
 *  Tests all sensors on the board to see that each subsystem works:
 *   - 12x WS2812B RGB LEDs
 *   - LSM6DS3 accelerometer/gyroscope (I2C)
 *   - APDS-9306-065 ambient light sensor (I2C, direct register access)
 *   - MPR121 12-channel capacitive touch controller (I2C)
 *   - 3x push buttons
 *
 *  ---------------------------------------------------------------------
 *  ARDUINO IDE SETUP
 *  ---------------------------------------------------------------------
 *  1. Board package: "esp32" by Espressif Systems (Boards Manager)
 *  2. Board: "ESP32C3 Dev Module"
 *  3. Tools -> USB CDC On Boot: "Enabled"   <-- required, or Serial won't
 *     appear over the native USB port
 *  4. This board has no USB-UART bridge, so there is no auto-reset circuit.
 *     To upload: hold BOOT (SW2), tap RESET (SW1), release BOOT, THEN
 *     click Upload. Ensure all serial monitors are closed before uploading.
 *  5. After uploading is completed, tap RESET (SW1)
 *
 *  LIBRARIES (all installable via Library Manager)
 *   - "Adafruit NeoPixel"            (WS2812B)
 *   - "Adafruit LSM6DS"              (IMU — pulls in Adafruit_LSM6DS3TRC)
 *   - "Adafruit Unified Sensor"      (dependency of the above)
 *   - "Adafruit MPR121"              (capacitive touch)
 *  (The APDS-9306-065 light sensor has no common Arduino library, so it's
 *   talked to directly over Wire — this also doubles as a simple example
 *   of raw I2C register access.)
 *
 *  ---------------------------------------------------------------------
 *  BOARD PINOUT (OSCD Demo PCB Rev 1.0)
 *  ---------------------------------------------------------------------
 *  I2C SDA          GPIO7   (LSM6DS3 @0x6A, APDS-9306-065 @0x52, MPR121 @0x5A)
 *  I2C SCL          GPIO6
 *  WS2812 data      GPIO8   (12 LEDs)
 *  Button SW3       GPIO1   (active low)
 *  Button SW4       GPIO0   (active low)
 *  Button SW5       GPIO2   (active low)
 *  MPR121 IRQ       GPIO10  (not used here)
 *  LSM6DS3 INT1     GPIO4   (not used here)
 *  LSM6DS3 INT2     GPIO5   (not used here)
 */

#include <Wire.h>
#include <Adafruit_NeoPixel.h>
#include <Adafruit_LSM6DS3TRC.h>
#include <Adafruit_MPR121.h>

// ---------- Pin definitions ----------
#define PIN_SDA 7
#define PIN_SCL 6

#define PIN_LED_DATA 8
#define NUM_LEDS 12

#define NUM_BTNS 3
#define PIN_BTN_SW3 1
#define PIN_BTN_SW4 0
#define PIN_BTN_SW5 2

#define NUM_TOUCH 12

#define MPR121_ADDR 0x5A
#define LSM6DS3_ADDR 0x6A
#define APDS9306_ADDR 0x52

// --- APDS-9306-065 helper functions ---
#include <APDS9306.h>

// ---------- Objects ----------
Adafruit_NeoPixel strip(NUM_LEDS, PIN_LED_DATA, NEO_GRB + NEO_KHZ800);
Adafruit_LSM6DS3TRC imu;
Adafruit_MPR121 touch = Adafruit_MPR121();

bool imuOk = false;
bool touchOk = false;
bool alsOk = false;

uint32_t lastSensorPrint = 0;

// ======================================================================
//  Setup
// ======================================================================
void setup() {
  // --- Serial ---
  Serial.begin(115200);
  Serial.setTxTimeoutMs(0); // prevent USB CDC port from blocking the sketch
  uint32_t t0 = millis();
  while (!Serial && millis() - t0 < 3000) {
    delay(10);
  }  // give USB CDC time to enumerate

  // --- buttons ---
  pinMode(PIN_BTN_SW3, INPUT);  // buttons have external pull-up resistors
  pinMode(PIN_BTN_SW4, INPUT);
  pinMode(PIN_BTN_SW5, INPUT);

  // --- led strip ---
  strip.begin();
  strip.setBrightness(60);
  strip.show();  // all off

  // --- I2C ---
  Wire.begin(PIN_SDA, PIN_SCL);
  Wire.setClock(400000);
  delay(100);

  // --- IMU ---
  if (imu.begin_I2C(LSM6DS3_ADDR, &Wire)) {
    imuOk = true;
  }

  // --- Ambient light sensor ---
  alsOk = apds9306Init();
  Serial.println(alsOk ? "[OK]   APDS-9306-065 light sensor responding"
                       : "[FAIL] APDS-9306-065 light sensor not responding");

  // --- Capacitive touch ---
  if (touch.begin(MPR121_ADDR, &Wire)) {
    touchOk = true;
    touch.setAutoconfig(true);
  }

  // --- startup animation ---
  for (uint16_t i = 0; i < 2 * NUM_LEDS; i++) {
    strip.rainbow(i * 0x10000 / NUM_LEDS, 1, 255, 255, true);
    strip.show();
    delay(100);
  }
  strip.clear();
  strip.show();
}

// ======================================================================
//  Main loop
// ======================================================================
void loop() {
  handleButtons();

  if (alsOk)
    handleAls();

  if (imuOk)
    handleImu();

  if (touchOk)
    handleTouch();

  if (Serial && millis() - lastSensorPrint > 500) {
    lastSensorPrint = millis();
    printSensorReadings();
  }
}

// ---------- Buttons -> LED flashes  ----------
void handleButtons() {
  static bool lastState[NUM_BTNS] = { true, true, true };  // pulled up = true when idle
  int pins[NUM_BTNS] = { PIN_BTN_SW3, PIN_BTN_SW4, PIN_BTN_SW5 };

  for (uint8_t i = 0; i < NUM_BTNS; i++) {
    bool state = digitalRead(pins[i]);
    if (state != lastState[i]) {
      uint8_t first_led = i * NUM_LEDS / NUM_BTNS;       // first led of the segment
      uint8_t last_led = (i + 1) * NUM_LEDS / NUM_BTNS;  // first led of the next segment
      uint16_t hue = i * 0x10000 / NUM_BTNS;

      if (!state) {  // pressed
        for (uint8_t j = first_led; j < last_led; j++) {
          strip.setPixelColor(j, strip.gamma32(strip.ColorHSV(hue, 255, 255)));
        }
      } else {  // released
        for (uint8_t j = first_led; j < last_led; j++) {
          strip.setPixelColor(j, 0);
        }
      }
      strip.show();
    }
    lastState[i] = state;
  }
}

// ---------- Ambient light -> LED brightness ----------
void handleAls() {
  const uint16_t max_lux = 10000;
  uint8_t brightness = map(constrain(apds9306ReadALS(), 0, max_lux), 0, max_lux, 0, 255);
  strip.setBrightness(brightness);
}

// ---------- Orientation -> LED mapping ----------
void handleImu() {
  static uint8_t lastLed = 0;
  const uint16_t hue = 0;

  float accel_x;
  float accel_y;
  float accel_z;

  imu.readAcceleration(accel_x, accel_y, accel_z);
  float angle = atan2(-accel_y, accel_x) + M_PI;
  float magsq = (accel_y*accel_y + accel_x*accel_x);
  
  uint8_t led = ((uint8_t) round(angle/(2*M_PI)*NUM_LEDS)) % NUM_LEDS;
  uint8_t val = (uint8_t) (magsq*255.);

  strip.setPixelColor(led, strip.ColorHSV(hue,255,val));

  if (led != lastLed) {
    strip.setPixelColor(lastLed, 0);
    strip.show();
    lastLed = led;
  }
}

// ---------- Capacitive touch -> LED mapping ----------
void handleTouch() {
  static uint16_t lastTouched = 0;
  const uint8_t led_map[NUM_TOUCH] = { 3, 2, 1, 0, 11, 10, 9, 8, 7, 6, 5, 4 };

  uint16_t currTouched = touch.touched();

  for (int i = 0; i < NUM_TOUCH; i++) {
    bool isTouched = currTouched & (1 << i);  // read bitmask
    bool wasTouched = lastTouched & (1 << i);

    if (isTouched) {                                                       // while pressed
      uint8_t val = (touch.baselineData(i) - touch.filteredData(i)) >> 2;  // touch sensor data, converted from 10 bit to 8 bit
      strip.setPixelColor(led_map[i], strip.ColorHSV(0, 0, val));
      strip.show();
    }

    if (!isTouched && wasTouched) {  // released
      uint8_t led = i % NUM_LEDS;
      strip.setPixelColor(led_map[i], 0);
      strip.show();
    }
  }
  lastTouched = currTouched;
}

// ---------- Periodic IMU / light sensor printout ----------
void printSensorReadings() {
  Serial.print("IMU    ");
  if (imuOk) {
    sensors_event_t accel;
    sensors_event_t gyro;
    sensors_event_t temp;
    imu.getEvent(&accel, &gyro, &temp);

    Serial.print("T[degC]=");
    Serial.print(temp.temperature);

    Serial.print("  accel[m/s^2] X=");
    Serial.print(accel.acceleration.x, 2);
    Serial.print(" Y=:");
    Serial.print(accel.acceleration.y, 2);
    Serial.print(" Z=");
    Serial.print(accel.acceleration.z, 2);

    /* Display the results (rotation is measured in rad/s) */
    Serial.print("  gyro[rad/s] X= ");
    Serial.print(gyro.gyro.x, 1);
    Serial.print(" Y=");
    Serial.print(gyro.gyro.y, 1);
    Serial.print(" Z=");
    Serial.print(gyro.gyro.z, 1);
  } else {
    Serial.print("not detected");
  }
  Serial.println();

  Serial.print("ALS    ");
  if (alsOk) {
    Serial.print("value[counts]=");
    Serial.print(apds9306ReadALS());
    Serial.println(" (roughly proportional to lux)");
  } else {
    Serial.println("not detected");
  }
  Serial.println();

  Serial.print("TOUCH  ");
  if (touchOk) {
    Serial.print("value[counts]");
    for (uint8_t i = 0; i < NUM_TOUCH; i++) {
      Serial.print("pad");
      Serial.print(i);
      Serial.print(" ");
      Serial.print(touch.baselineData(i) - touch.filteredData(i));
      Serial.print(" ");
    }
    Serial.println();
  } else {
    Serial.println("not detected");
  }
}

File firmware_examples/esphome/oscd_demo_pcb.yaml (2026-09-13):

# =============================================================================
#  OSCD Demo PCB (rev 1.0) — ESPHome configuration
#  Open Science Community Delft — CERN-OHL-P
#
#  Exposes every peripheral on the board to Home Assistant:
#    - 12x WS2812B ring          (light)
#    - LSM6DS3 accel/gyro/temp   (motion + sensor)
#    - APDS-9306-065 ambient light (sensor)
#    - MPR121 12-channel touch   (binary_sensor)
#    - 3x push buttons           (binary_sensor)
#
#  FIRST FLASH
#    The board has no auto-reset circuit, so the very first flash must be over
#    USB with the bootloader entered by hand:
#        hold BOOT (SW2) -> tap RESET (SW1) -> release BOOT
#        esphome run oscd_demo_pcb.yaml
#    After that, OTA takes over and the buttons are never needed again.
#
#  Copy secrets.yaml.example to secrets.yaml and fill it in first.
# =============================================================================

substitutions:
  name: oscd-demo-pcb
  friendly_name: OSCD Demo PCB

esphome:
  name: ${name}
  friendly_name: ${friendly_name}
  # The lsm6ds motion platform landed in ESPHome 2026.6.0. Older versions will
  # fail validation on the `motion:` block below rather than silently misbehave.
  min_version: 2026.6.0

esp32:
  board: esp32-c3-devkitm-1   # ESP32-C3, 4 MB flash, no PSRAM — matches ESP32-C3-MINI-1
  variant: esp32c3
  framework:
    type: esp-idf

# The C3 has no USB-UART bridge; logging goes over the native USB Serial/JTAG
# peripheral. This is the default on C3 and can be omitted — it is spelled out
# here because it is the single thing people get wrong on this chip.
logger:
  hardware_uart: USB_SERIAL_JTAG

api:
  encryption:
    key: !secret api_encryption_key

ota:
  - platform: esphome
    password: !secret ota_password

wifi:
  ssid: !secret wifi_ssid
  password: !secret wifi_password
  ap:
    ssid: "${friendly_name} Fallback"
    password: !secret fallback_password

captive_portal:

# -----------------------------------------------------------------------------
#  Web server — the board's own UI, at http://<device-ip>/
#
#  This is what makes the board demonstrable away from Home Assistant: if it
#  cannot reach a known network it raises its own AP (see `wifi: ap:` above),
#  and you browse to http://192.168.4.1/ to get every entity below, live.
#
#  `local: true` is the load-bearing setting. Without it the page pulls its
#  CSS/JS from esphome.io, which is exactly what you will not have while
#  connected to the board's own access point. It costs flash; see README.
# -----------------------------------------------------------------------------
web_server:
  port: 80
  version: 3
  local: true
  ota: false          # OTA stays available via captive_portal and the HA API
  include_internal: false

# -----------------------------------------------------------------------------
#  I2C — one 400 kHz bus shared by all three sensors
# -----------------------------------------------------------------------------
i2c:
  sda: GPIO7
  scl: GPIO6
  frequency: 400kHz
  scan: true

# -----------------------------------------------------------------------------
#  LED ring — 12x WS2812B-2020
#  D1 sits at 9 o'clock; the chain runs clockwise D1 -> D12.
# -----------------------------------------------------------------------------
light:
  - platform: esp32_rmt_led_strip
    id: ring
    name: "Ring"
    pin:
      number: GPIO8
      # GPIO8 is a strapping pin, held high at reset by R3 (10k to 3V3) so the
      # chip boots normally. Driving it afterwards is intended, not an accident.
      ignore_strapping_warning: true
    num_leds: 12
    chipset: WS2812
    channel_colors: GRB
    use_psram: false      # ESP32-C3-MINI-1 has no PSRAM
    max_refresh_rate: 16ms
    default_transition_length: 250ms
    effects:
      - addressable_rainbow:
          name: "Rainbow"
      - addressable_scan:
          name: "Scan"
      - pulse:
          name: "Pulse"
      # Mirrors the Arduino demo: each touch electrode lights the LED nearest to
      # it. The map is lifted from test_sensors.ino, where it was worked out
      # against the physical pad and LED positions.
      - addressable_lambda:
          name: "Touch trace"
          update_interval: 30ms
          lambda: |-
            static const uint8_t led_map[12] = {3, 2, 1, 0, 11, 10, 9, 8, 7, 6, 5, 4};
            static esphome::binary_sensor::BinarySensor *pads[12] = {
              id(touch_0), id(touch_1), id(touch_2),  id(touch_3),
              id(touch_4), id(touch_5), id(touch_6),  id(touch_7),
              id(touch_8), id(touch_9), id(touch_10), id(touch_11),
            };
            it.all() = Color::BLACK;
            for (uint8_t i = 0; i < 12; i++) {
              if (pads[i]->state) {
                it[led_map[i]] = current_color;
              }
            }
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

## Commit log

2026-09-09 folder for production files
    [bom.csv, designators.csv, positions.csv]
2026-09-09 interactive bom
2026-09-12 add info presentation
    [OSCD_demo_PCB.kicad_pcb]
2026-09-13 Create schematic.pdf
    add pdf schematic
2026-09-13 added LED chaser project
    [BOM-led_chaser_SMD.csv, BOM-led_chaser_THT.csv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]
